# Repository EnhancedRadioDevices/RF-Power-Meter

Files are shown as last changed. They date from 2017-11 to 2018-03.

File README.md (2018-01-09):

Enhanced Radio Devices - RF Power Meter
=======

The ERD RF Power Meter is designed as an affordable RF Power Meter for use in cases where the precision of expensive professional equipment is not required.

The device is available to the host system as a USB serial device, which when accessed automatically prints the measured RF level.

This repository contains the source code to be compiled with AVR-GCC, and uploaded to the device via ATMEL's FLIP programmer or the dfu-programmer utility.

## Drivers
The Power Meter board is automatically recognized as a USB serial device under OSX and Linux, however, windows requires a driver to associate the device with the built in USB serial device drivers.

When first attaching the device to a windows based host, windows will attempt to find a driver and fail. You may then specify a driver. This is provided in ERD_RF_Power_Meter.inf.

Once you have installed the driver, the Power Meter will register as a COM port device under windows, and you may access it with any serial/terminal application of your preference.

### Windows Users
During the driver installation process on Windows 8 operating systems and above you may encounter *"The third-party INF does not contain digital signature information"* preventing the installation of the included driver.  The steps below outline the process for disabling driver signature enforcement on Windows 8/8.1 systems.

**NOTE:** If your system uses BitLocker Drive Encryption, you will need your encryption key to gain access to advanced settings to disable driver signature enforcement.

Windows 8 - Navigate to PC settings > General and look for the *Advanced startup* dialog.  Click the **Restart now** button to access the advanced startup settings.  Your system will now reboot.

Windows 8.1 - Navigate to PC settings > Update and Recovery > Recovery and look for the *Advanced startup* dialog.  Click the **Restart now** button to access the advanced startup settings.  Your system will now reboot.

After rebooting select Troubleshoot > Advanced options > Startup Settings, click the **Restart** button, your machine will reboot a second time.

After rebooting a second time you should be presented with the Windows Startup Settings dialog, choose *Disable driver signature enforcement* by pressing number `7` on your keyboard.  Your machine will reboot automatically.

Once rebooted, you should now be able to install the drviers as outlined above.  Once the appropriate driver is selected you will see a Windows Security dialog warning against the installation of the unsigned driver.  Click **Install this driver software anyway** to complete the driver installation.

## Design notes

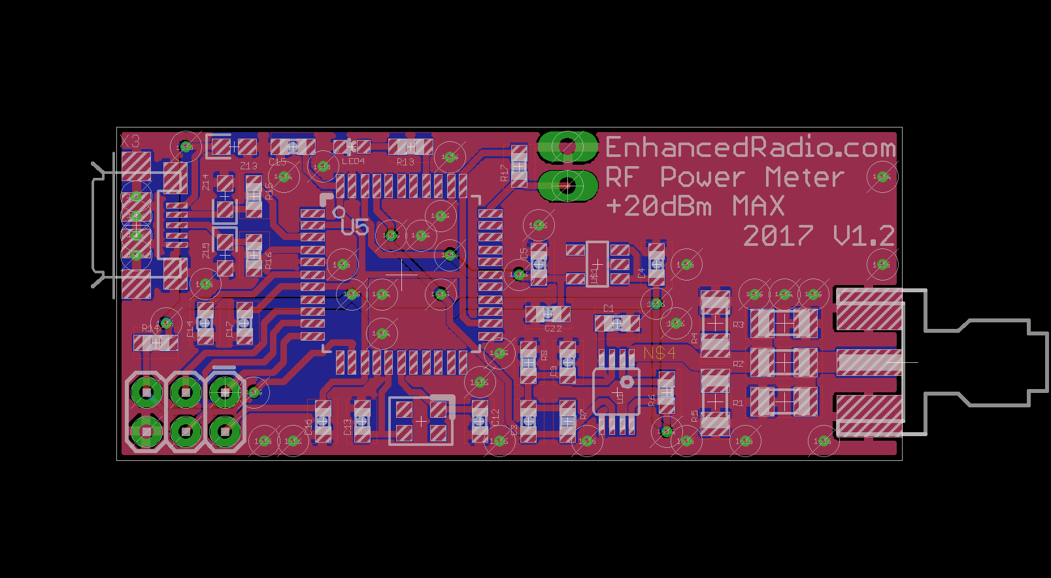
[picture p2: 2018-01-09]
Hardware/Board.png

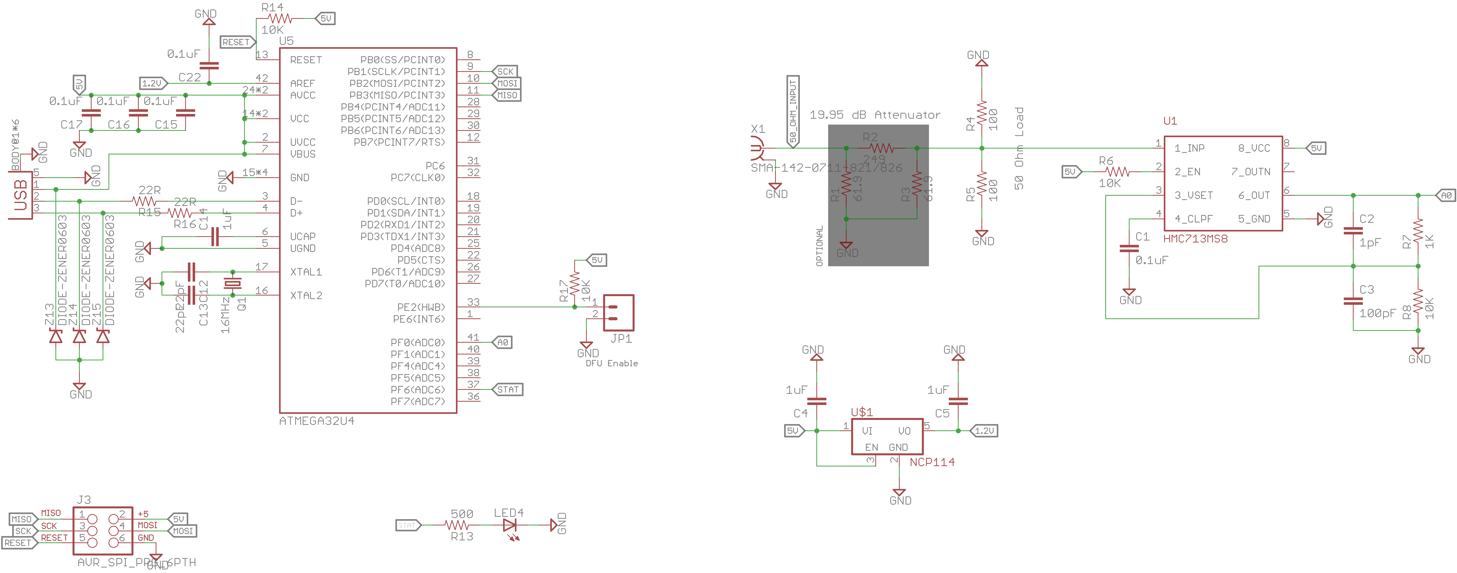
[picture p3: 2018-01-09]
Hardware/Schematic.png

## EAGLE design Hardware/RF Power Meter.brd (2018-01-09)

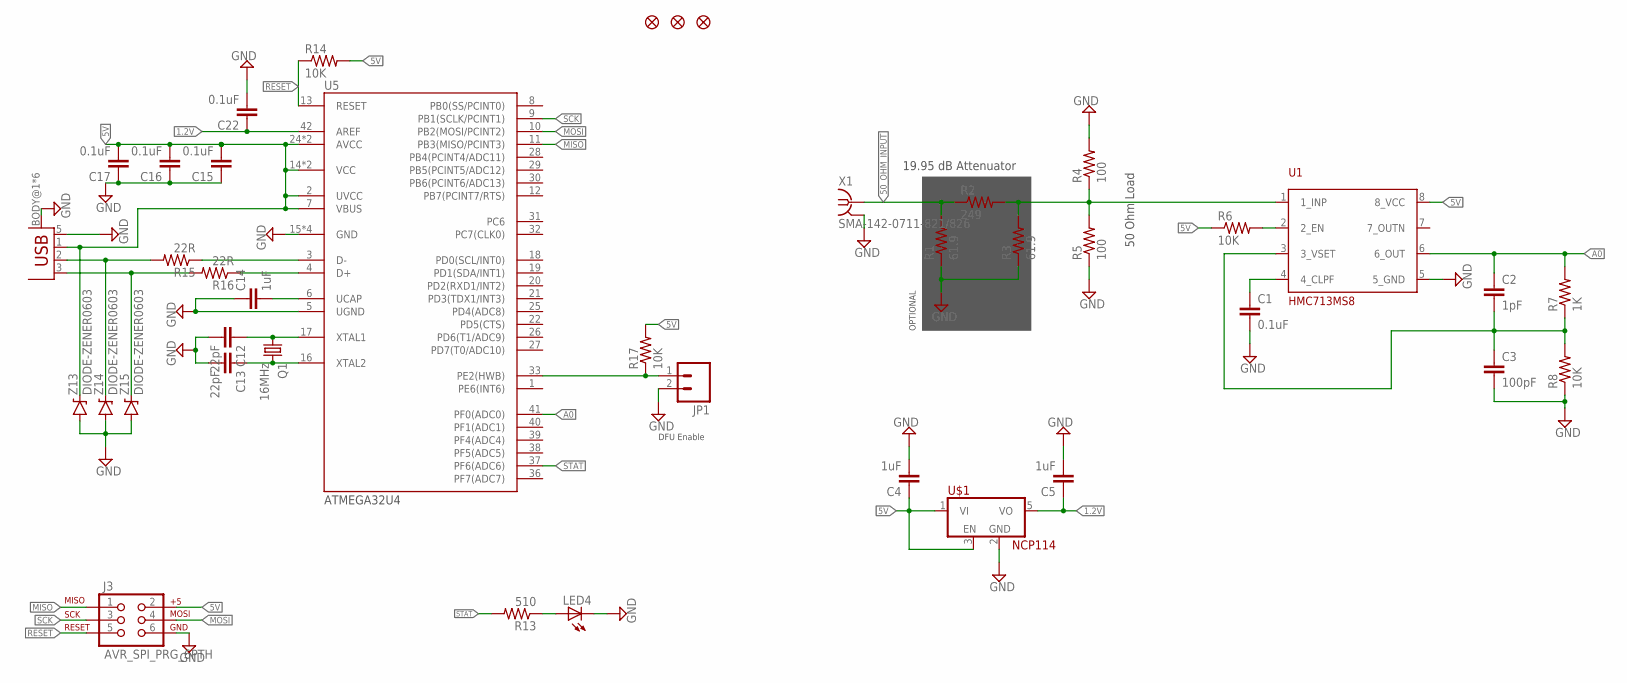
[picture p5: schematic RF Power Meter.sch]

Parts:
C1, C15, C16, C17, C22: 0.1uF; 0603-CAP
C2: 1pF; 0603-CAP
C3: 100pF; 0603-CAP
C4, C5, C14: 1uF; 0603-CAP
C12, C13: 22pF; 0603-CAP
J3: AVR_SPI_PRG_6PTH; 2X3
JP1: M02PTH3; 1X02_LONGPADS
JP2, JP3, JP4: FIDUCIAL1X2; FIDUCIAL-1X2
LED4: LED0603; LED-0603
Q1: 16MHz; CRYSTAL_3.2X2.5
R1, R3: 61.9; 1206
R2: 249; 1206
R4, R5: 100; 1206
R6, R8, R14, R17: 10K; 0603-RES
R7: 1K; 0603-RES
R13: 510; 0603-RES
R15, R16: 22R; 0603-RES
U1: HMC713MS8; MSOP-8
U5: ATMEGA32U4; TQFP-44
U$1: NCP114; SOT-23-5
X1: SMA-142-0711-821/826; J502-ND-142-0711-821/826
X3: USB-MICROB; USB-MICROB-10118192
Z13, Z14, Z15: DIODE-ZENER0603; 0603-DIODE

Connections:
1.2V: C5.1, C22.1, U5.42 (AREF), U$1.5 (VO)
5V: C4.1, C15.2, C16.2, C17.2, J3.2, R6.1, R14.2, R17.2, U1.8 (8_VCC), U5.2 (UVCC), U5.7 (VBUS), U5.14 (VCC), U5.24 (AVCC), U5.34 (VCC), U5.44 (AVCC), U$1.1 (VI), U$1.3 (EN), X3.1 (VBUS), Z13.C
50_OHM_INPUT: R1.2, R2.1, X1.1
A0: C2.1, R7.2, U1.6 (6_OUT), U5.41 (PF0(ADC0))
GND: C1.2, C3.2, C4.2, C5.2, C12.2, C13.2, C14.1, C15.1, C16.1, C17.1, C22.2, J3.6, JP1.2, LED4.C, R1.1, R3.1, R4.2, R5.1, R8.1, U1.5 (5_GND), U5.5 (UGND), U5.15 (GND), U5.23 (GND), U5.35 (GND), U5.43 (GND), U$1.2 (GND), X1.G@1 (2), X1.G@2 (2), X1.G@3 (2), X1.G@4 (2), X3.5 (GND), X3.BODY@1 (BODY), X3.BODY@2 (BODY), X3.BODY@3 (BODY), X3.BODY@4 (BODY), X3.BODY@5 (BODY), X3.BODY@6 (BODY), Z13.A, Z14.A, Z15.A
MISO: J3.1, U5.11 (PB3(MISO/PCINT3))
MOSI: J3.4, U5.10 (PB2(MOSI/PCINT2))
unnamed: R2.2, R3.2, R4.1, R5.2, U1.1 (1_INP)
unnamed: R6.2, U1.2 (2_EN)
unnamed: C1.1, U1.4 (4_CLPF)
unnamed: C2.2, C3.1, R7.1, R8.2, U1.3 (3_VSET)
unnamed: LED4.A, R13.1
unnamed: C12.1, Q1.P$1 (1), U5.17 (XTAL1)
unnamed: C13.1, Q1.P$3 (2), U5.16 (XTAL2)
unnamed: R15.2, X3.2 (D-), Z14.C
unnamed: C14.2, U5.6 (UCAP)
unnamed: R16.2, X3.3 (D+), Z15.C
unnamed: R16.1, U5.4 (D+)
unnamed: R15.1, U5.3 (D-)
unnamed: JP1.1, R17.1, U5.33 (PE2(HWB))
RESET: J3.5, R14.1, U5.13 (RESET)
SCK: J3.3, U5.9 (PB1(SCLK/PCINT1))
STAT: R13.2, U5.37 (PF6(ADC6))

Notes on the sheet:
OPTIONAL
19.95 dB Attenuator
50 Ohm Load
DFU Enable

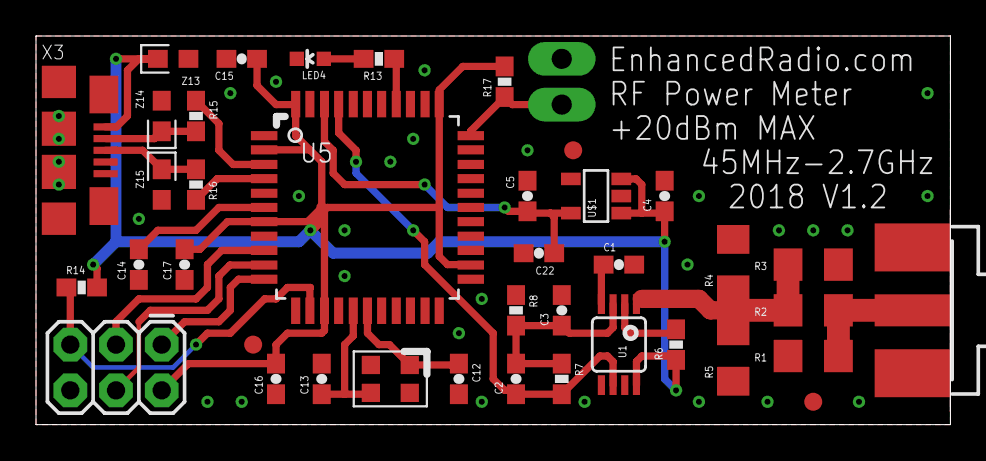
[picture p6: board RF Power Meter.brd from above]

Board: 2 copper layers, 50.8 x 21.6 mm, 40 parts (0 on the bottom side), 23 nets.

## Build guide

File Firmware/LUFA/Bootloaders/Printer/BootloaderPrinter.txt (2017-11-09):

/** \file
 *
 *  This file contains special DoxyGen information for the generation of the main page and other special
 *  documentation pages. It is not a project source file.
 */

/** \mainpage Printer Class USB AVR Bootloader
 *
 *  \section Sec_Compat Demo Compatibility:
 *
 *  The following list indicates what microcontrollers are compatible with this demo.
 *
 *  \li Series 7 USB AVRs (AT90USBxxx7)
 *  \li Series 6 USB AVRs (AT90USBxxx6)
 *  \li Series 4 USB AVRs (ATMEGAxxU4)
 *  \li Series 2 USB AVRs (AT90USBxx2, ATMEGAxxU2)
 *
 *  \section Sec_Info USB Information:
 *
 *  The following table gives a rundown of the USB utilization of this demo.
 *
 *  <table>
 *   <tr>
 *    <td><b>USB Mode:</b></td>
 *    <td>Device</td>
 *   </tr>
 *   <tr>
 *    <td><b>USB Class:</b></td>
 *    <td>Printer Class</td>
 *   </tr>
 *   <tr>
 *    <td><b>USB Subclass:</b></td>
 *    <td>Printer Subclass</td>
 *   </tr>
 *   <tr>
 *    <td><b>Relevant Standards:</b></td>
 *    <td>USBIF Printer Class Standard</td>
 *   </tr>
 *   <tr>
 *    <td><b>Supported USB Speeds:</b></td>
 *    <td>Full Speed Mode</td>
 *   </tr>
 *  </table>
 *
 *  \section Sec_Description Project Description:
 *
 *  This bootloader enumerates to the host as a Generic Text Only Printer device, capable of reading and parsing
 *  "printed" plain-text Intel HEX files to load firmware onto the AVR.
 *
 *  Out of the box this bootloader builds for the AT90USB1287 with an 8KB bootloader section size, and will fit
 *  into 4KB of bootloader space. If you wish to alter this size and/or change the AVR model, you will need to
 *  edit the MCU, FLASH_SIZE_KB and BOOT_SECTION_SIZE_KB values in the accompanying makefile.
 *
 *  When the bootloader is running, the board's LED(s) will flash at regular intervals to distinguish the
 *  bootloader from the normal user application.
 *
 *  \section Sec_Running Running the Bootloader
 *
 *  On the USB AVR8 devices, setting the \c HWBE device fuse will cause the bootloader to run if the \c HWB pin of
 *  the AVR is grounded when the device is reset.
 *
 *  The are two behaviours of this bootloader, depending on the device's fuses:
 *
 *  <b>If the device's BOOTRST fuse is set</b>, the bootloader will run any time the system is reset from
 *  the external reset pin, unless no valid user application has been loaded. To initiate the bootloader, the
 *  device's external reset pin should be grounded momentarily.
 *
 *  <b>If the device's BOOTRST fuse is not set</b>, the bootloader will run only if initiated via a software
 *  jump, or if the \c HWB pin was low during the last device reset (if the \c HWBE fuse is set).
 *
 *  For board specific exceptions to the above, see below.
 *
 *  \subsection SSec_XPLAIN Atmel Xplain Board
 *  Ground the USB AVR JTAG's \c TCK pin to ground when powering on the board to start the bootloader. This assumes the
 *  \c HWBE fuse is cleared and the \c BOOTRST fuse is set as the HWBE pin is not user accessible on this board.
 *
 *  \subsection SSec_Leonardo Arduino Leonardo Board
 *  Ground \c IO13 when powering the board to start the bootloader. This assumes the \c HWBE fuse is cleared and the
 *  \c BOOTRST fuse is set as the HWBE pin is not user accessible on this board.
 *
 *  \section Sec_Installation Driver Installation
 *
 *  This bootloader uses the Generic Text-Only printer drivers inbuilt into all modern operating systems, thus no
 *  additional drivers need to be supplied for correct operation.
 *
 *  \section Sec_HostApp Host Controller Application
 *
 *  This bootloader is compatible with Notepad under Windows, and the command line \c lpr utility under Linux.
 *
 *  \subsection SSec_Notepad Notepad (Windows)
 *
 *  While most text applications under Windows will be compatible with the bootloader, the inbuilt Notepad utility
 *  is recommended as it will introduce minimal formatting changes to the output stream. To program with Notepad,
 *  open the target HEX file and print it to the Generic Text Only printer device the bootloader creates.
 *
 *  \subsection SSec_LPR LPR (Linux)
 *
 *  While the CUPS framework under Linux will enumerate the bootloader as a Generic Text-Only printer, many
 *  applications will refuse to print to the device due to the lack of rich formatting options available. As a result,
 *  under Linux HEX files must be printed via the low level \c lpr utility instead.
 *
 *  \code
 *  cat Mouse.hex | lpr
 *  \endcode
 *
 *  \section Sec_API User Application API
 *
 *  Several user application functions for FLASH and other special memory area manipulations are exposed by the bootloader,
 *  allowing the user application to call into the bootloader at runtime to read and write FLASH data.
 *
 *  By default, the bootloader API jump table is located 32 bytes from the end of the device's FLASH memory, and follows the
 *  following layout:
 *
 *  \code
 *  #define BOOTLOADER_API_TABLE_SIZE          32
 *  #define BOOTLOADER_API_TABLE_START         ((FLASHEND + 1UL) - BOOTLOADER_API_TABLE_SIZE)
 *  #define BOOTLOADER_API_CALL(Index)         (void*)((BOOTLOADER_API_TABLE_START + (Index * 2)) / 2)
 *
 *  void    (*BootloaderAPI_ErasePage)(uint32_t Address)               = BOOTLOADER_API_CALL(0);
 *  void    (*BootloaderAPI_WritePage)(uint32_t Address)               = BOOTLOADER_API_CALL(1);
 *  void    (*BootloaderAPI_FillWord)(uint32_t Address, uint16_t Word) = BOOTLOADER_API_CALL(2);
 *  uint8_t (*BootloaderAPI_ReadSignature)(uint16_t Address)           = BOOTLOADER_API_CALL(3);
 *  uint8_t (*BootloaderAPI_ReadFuse)(uint16_t Address)                = BOOTLOADER_API_CALL(4);
 *  uint8_t (*BootloaderAPI_ReadLock)(void)                            = BOOTLOADER_API_CALL(5);
 *  void    (*BootloaderAPI_WriteLock)(uint8_t LockBits)               = BOOTLOADER_API_CALL(6);
 *
 *  #define BOOTLOADER_MAGIC_SIGNATURE_START   (BOOTLOADER_API_TABLE_START + (BOOTLOADER_API_TABLE_SIZE - 2))
 *  #define BOOTLOADER_MAGIC_SIGNATURE         0xDCFB
 *
 *  #define BOOTLOADER_CLASS_SIGNATURE_START   (BOOTLOADER_API_TABLE_START + (BOOTLOADER_API_TABLE_SIZE - 4))
 *  #define BOOTLOADER_PRINTER_SIGNATURE       0xDF20
 *
 *  #define BOOTLOADER_ADDRESS_START           (BOOTLOADER_API_TABLE_START + (BOOTLOADER_API_TABLE_SIZE - 8))
 *  #define BOOTLOADER_ADDRESS_LENGTH          4
 *  \endcode
 *
 *  From the application the API support of the bootloader can be detected by reading the FLASH memory bytes located at address
 *  \c BOOTLOADER_MAGIC_SIGNATURE_START and comparing them to the value \c BOOTLOADER_MAGIC_SIGNATURE. The class of bootloader
 *  can be determined by reading the FLASH memory bytes located at address \c BOOTLOADER_CLASS_SIGNATURE_START and comparing them
 *  to the value \c BOOTLOADER_PRINTER_SIGNATURE. The start address of the bootloader can be retrieved by reading the bytes of FLASH
 *  memory starting from address \c BOOTLOADER_ADDRESS_START.
 *
 *  \subsection SSec_API_MemLayout Device Memory Map
 *  The following illustration indicates the final memory map of the device when loaded with the bootloader.
 *
 *  \verbatim
 *  +----------------------------+ 0x0000
 *  |                            |
 *  |                            |
 *  |                            |
 *  |                            |
 *  |                            |
 *  |                            |
 *  |                            |
 *  |                            |
 *  |      User Application      |
 *  |                            |
 *  |                            |
 *  |                            |
 *  |                            |
 *  |                            |
 *  |                            |
 *  |                            |
 *  +----------------------------+ FLASHEND - BOOT_SECTION_SIZE
 *  |                            |
 *  |   Bootloader Application   |
 *  | (Not User App. Accessible) |
 *  |                            |
 *  +----------------------------+ FLASHEND - 96
 *  |   API Table Trampolines    |
 *  | (Not User App. Accessible) |
 *  +----------------------------+ FLASHEND - 32
 *  |    Bootloader API Table    |
 *  |   (User App. Accessible)   |
 *  +----------------------------+ FLASHEND - 8
 *  |   Bootloader ID Constants  |
 *  |   (User App. Accessible)   |
 *  +----------------------------+ FLASHEND
 *  \endverbatim
 *
 *
 *  \section Sec_KnownIssues Known Issues:
 *
 *  \par On Linux machines, new firmware fails to be sent to the device via CUPS.
 *  Only a limited subset of normal printer functionality is exposed via the
 *  bootloader, causing CUPS to reject print requests from applications that
 *  are unable to handle true plain-text printing. For best results, the low
 *  level \c lpr command should be used to print new firmware to the bootloader.
 *
 *  \section Sec_Options Project Options
 *
 *  The following defines can be found in this demo, which can control the demo behaviour when defined, or changed in value.
 *
 *  <table>
 *   <tr>
 *    <td>
 *     None
 *    </td>
 *   </tr>
 *  </table>
 */

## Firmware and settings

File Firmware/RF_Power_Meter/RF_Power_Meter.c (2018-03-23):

/* Enhanced Radio Devices */
/* 2018 by Nigel Vander Houwen <nigel@enhancedradio.com> */

#include "RF_Power_Meter.h"

// Main Scheduling Interrupt
ISR(TIMER1_COMPA_vect){
	timer++;

	if ((timer) % (READ_RF_DELAY * PRINTING_RATE) == 0){ schedule_read_rf = 1; }
}

// Main program entry point.
int main(void) {
	// Store our reset vector for reference
	// See ATmega32u4 Datasheet p.59 for values
	BOOT_RESET_VECTOR = MCUSR;
	MCUSR = 0;

	// Initialize some variables
	int16_t BYTE_IN = -1;
	DATA_IN = malloc(DATA_BUFF_LEN);

	// Set up timer 1 for 0.25s interrupts
	TCCR1A = 0b00000000; // No pin changes on compare match
	TCCR1B = 0b00001010; // Clear timer on compare match, clock /8
	TCCR1C = 0b00000000; // No forced output compare
	OCR1A = 31250; // Set timer clear at this count value
	TCNT1 = 0;
	TIMSK1 = 0b00000010; // Enable interrupts on the A compare match

	Watchdog_Disable();
	wdt_reset();
	Watchdog_Enable();

	// Divide 16MHz crystal down to 1MHz for CPU clock.
	clock_prescale_set(clock_div_16);

	// Init USB hardware and create a regular character stream for the
	// USB interface so that it can be used with the stdio.h functions
	USB_Init();
	CDC_Device_CreateStream(&VirtualSerial_CDC_Interface, &USBSerialStream);
	run_lufa();

	// Enable interrupts
	GlobalInterruptEnable();

	// Short delay during startup
	_delay_ms(2000);

	// Print startup message
	printPGMStr(PSTR(SOFTWARE_STR));
	fprintf(&USBSerialStream, " V%s,%s", HARDWARE_VERS, SOFTWARE_VERS);
	run_lufa();

	// Configure LED Pin
	DDRF |= (1 << LED);
	Set_LED(0);

	// Enable the ADC
	ADCSRA = (1<<ADEN) | (1<<ADPS2) | (1<<ADPS1) | (1<<ADPS0); // Enable ADC, clocked by /128 divider
	
	// Check that the EEPROM has been initialized
	if (eeprom_read_byte((uint8_t*)(EEPROM_OFFSET_EEPROM_INIT)) != EEPROM_VERS) {
		printPGMStr(PSTR("\r\nEEPROM not initialized. Initializing..."));
		run_lufa();
		EEPROM_Init();
		eeprom_update_byte((uint8_t*)(EEPROM_OFFSET_EEPROM_INIT), EEPROM_VERS);
	}
	
	// Load calibration values
	Load_RF_Calibration(1);
	
	run_lufa();

	INPUT_Clear();

// ~~~~~~~~~~~~~~~~~~~~~~~~~~~~~~~~~~~~~~~~~~~~
// ~~ Main system loop
// ~~~~~~~~~~~~~~~~~~~~~~~~~~~~~~~~~~~~~~~~~~~~

	for (;;) {
		// Read a byte from the USB serial stream
		BYTE_IN = CDC_Device_ReceiveByte(&VirtualSerial_CDC_Interface);

		// USB Serial stream will return <0 if no bytes are available.
		if (BYTE_IN >= 0) {
			// Echo the char we just received back out the serial stream so the user's 
			// console will display it.
			fputc(BYTE_IN, &USBSerialStream);

			// Switch on the input byte to determine what is is and what to do.
			switch (BYTE_IN) {
				case 8:
				case 127:
					// Handle Backspace chars.
					if (DATA_IN_POS > 0){
						DATA_IN_POS--;
						DATA_IN[DATA_IN_POS] = 0;
						printPGMStr(STR_Backspace);
					}
					break;

				case '\n':
				case '\r':
					// Newline, Parse our command
					INPUT_Parse();
					INPUT_Clear();
					break;

				case 3:
					// Ctrl-c bail out on partial command
					INPUT_Clear();
					break;
				
				case 27:
					// ESC Print menu
					PRINT_Help();
					INPUT_Clear();
				
				case 29:
					// Ctrl-] reset all eeprom values
					EEPROM_Reset();
					EEPROM_Init();
					INPUT_Clear();
					break;
					
				case 30:
					// Ctrl-^ jump into the bootloader
					// Disable the watchdog timer
					Watchdog_Disable();
					
					bootloader();
					break; // We should never get here...

				default:
					// Normal char buffering
					if (DATA_IN_POS < (DATA_BUFF_LEN - 1)) {
						DATA_IN[DATA_IN_POS] = BYTE_IN;
						DATA_IN_POS++;
						DATA_IN[DATA_IN_POS] = 0;
					} else {
						// Input is too long.
						printPGMStr(STR_Unrecognized);
						INPUT_Clear();
					}
					break;
			}
		}
		
		// Check for above threshold current usage
		if (schedule_read_rf && DATA_IN_POS == 0) {
			Set_LED(1);	
	
			// Collect ADC_AVG_POINTS samples and average them
			uint16_t average = 0;
			for (uint8_t i = 0; i < ADC_AVG_POINTS; i++) {
				average += ADC_Read_RF();
			}
			average = average / ADC_AVG_POINTS;
			
			// Convert the average reading into a voltage value referenced on ADC_V_REF
			float temp = (average * (ADC_V_REF / 1024.0));
			
			// Convert the voltage value into a dBm reading
			if (OUTPUTRAW == 0) {
				temp = (temp / RF_FREQ_SLOPE) - RF_FREQ_INTERCEPT + 19.95;
				fprintf(&USBSerialStream, "\r\n%.2f dBm", temp);
			} else {
				fprintf(&USBSerialStream, "\r\n%.3f V", temp);
			}
			
			schedule_read_rf = 0;
			
			Set_LED(0);
		}
		
		// Keep the LUFA USB stuff fed regularly.
		run_lufa();
		
		// Reset the watchdog
		wdt_reset();
	}
}

// ~~~~~~~~~~~~~~~~~~~~~~~~~~~~~~~~~~~~~~~~~~~~
// ~~ Command Parsing Functions
// ~~~~~~~~~~~~~~~~~~~~~~~~~~~~~~~~~~~~~~~~~~~~

// Flush out our data input buffer, reset our position variable, and print a new prompt.
static inline void INPUT_Clear(void) {
	memset(&DATA_IN[0], 0, sizeof(DATA_IN));
	DATA_IN_POS = 0;
	
	fprintf(&USBSerialStream, "\r\n\r\n");
}

// Parse out a single number argument
static inline long INPUT_Parse_num() {
	long temp = 0;
	uint8_t negative = 0;
	uint8_t num_started = 0;
	
	while (*DATA_IN != 0) {
		if (num_started == 0) { // Number hasn't started yet. Skip through non-number chars.
			if (*DATA_IN == '-') { negative = 1; num_started = 1; }
			if (*DATA_IN == '+') { negative = 0; num_started = 1; }
			if (*DATA_IN >= '0' && *DATA_IN <= '9') { temp = (temp * 10) + (*DATA_IN - '0'); num_started = 1; }
		} else { // Number has started. Continue reading until we hit a non-number.
			if (*DATA_IN >= '0' && *DATA_IN <= '9') {
				temp = (temp * 10) + (*DATA_IN - '0');
			} else {
				break;
			}
		}
		DATA_IN++;	
	}
	
	if (negative) { temp = temp * -1; }
	
	return temp;
}

// We've gotten a new command, parse out what they want.
static inline void INPUT_Parse(void) {
	// HELP - Print a basic help menu
	if (strncasecmp_P(DATA_IN, STR_Command_HELP, 4) == 0) {
		PRINT_Help();
		return;
	}
	// DEBUG - Print a report of debugging information, including EEPROM variables
	if (strncasecmp_P(DATA_IN, STR_Command_DEBUG, 10) == 0) {
		DEBUG_Dump();
		return;
	}
	// SETSLOPE - Update calibration slope value for the given frequency
	if (strncasecmp_P(DATA_IN, STR_Command_SETSLOPE, 8) == 0) {
		DATA_IN += 8;
		long span = INPUT_Parse_num();
		long slope = INPUT_Parse_num();
		if (span >= 0 && span <= 26 && slope >= 160 && slope <= 180) {
			EEPROM_Write_RF_Cal_Slope(span, (float)(slope / 10000.0));
			printPGMStr(STR_Slope_Set);
			return;
		}
	}
	// SETINTERCEPT - Update calibration intercept value for the given frequency	
	if (strncasecmp_P(DATA_IN, STR_Command_SETINTERCEPT, 12) == 0) {
		DATA_IN += 12;
		long span = INPUT_Parse_num();
		long intercept = INPUT_Parse_num();
		if (span >= 0 && span <= 26 && intercept >= 65 && intercept <= 75) {
			EEPROM_Write_RF_Cal_Intercept(span, intercept);
			printPGMStr(STR_Intercept_Set);
			return;
		}
	}
	// OUTPUTRAW - Toggle outputting raw voltage values instead of the calculated dBm values
	if (strncasecmp_P(DATA_IN, STR_Command_OUTPUTRAW, 9) == 0) {
		if (OUTPUTRAW == 0) {
			OUTPUTRAW = 1;
		} else {
			OUTPUTRAW = 0;
		}
		return;
	}
	// F - Set frequency to help calibrate readings
	if (*DATA_IN == 'F' || *DATA_IN == 'f') {
		DATA_IN += 1;
		uint16_t temp_freq = atoi(DATA_IN);
		if (temp_freq >= 1 && temp_freq < 2700) {
			printPGMStr(STR_Load_Cal);
			fprintf(&USBSerialStream, "%i", temp_freq);
			Load_RF_Calibration(temp_freq);
			return;
		}
	}
	// R - Set data printing rate
	if (*DATA_IN == 'R' || *DATA_IN == 'r') {
		DATA_IN += 1;
		uint16_t temp_rate = atoi(DATA_IN);
		if (temp_rate >= 1 && temp_rate <= 10) {
			printPGMStr(STR_Rate_Set);
			fprintf(&USBSerialStream, "%i seconds.", temp_rate);
			PRINTING_RATE = temp_rate;
			return;
		}
	}
	
	// If none of the above commands were recognized, print a generic error.
	printPGMStr(STR_Unrecognized);
}

// ~~~~~~~~~~~~~~~~~~~~~~~~~~~~~~~~~~~~~~~~~~~~
// ~~ Printing Functions
// ~~~~~~~~~~~~~~~~~~~~~~~~~~~~~~~~~~~~~~~~~~~~

// Print a summary of all ports status'
static inline void PRINT_Status(void) {

}

// Print a quick help command
static inline void PRINT_Help(void) {
	printPGMStr(STR_Help_Info);
}

// Print a PGM stored string
static inline void printPGMStr(PGM_P s) {
	char c;
	while((c = pgm_read_byte(s++)) != 0) fputc(c, &USBSerialStream);
}

// ~~~~~~~~~~~~~~~~~~~~~~~~~~~~~~~~~~~~~~~~~~~~
// ~~ EEPROM Functions
// ~~~~~~~~~~~~~~~~~~~~~~~~~~~~~~~~~~~~~~~~~~~~ 

// Reset all EEPROM values to 255
static inline void EEPROM_Reset(void) {
	for (uint16_t i = 0; i < 512; i++) {
		eeprom_update_byte((uint8_t*)(i), 255);
	}
}

// Initialize the EEPROM with default calibration values
static inline void EEPROM_Init(void) {
	for (uint8_t i = 0; i < 27; i++) {
		eeprom_update_byte((uint8_t*)(EEPROM_OFFSET_RF_CAL_SLOPE + i), RF_CAL_DEFAULTS_SLOPE[i]);
		eeprom_update_byte((uint8_t*)(EEPROM_OFFSET_RF_CAL_INTERCEPT + i), RF_CAL_DEFAULTS_INTERCEPT[i]);
	}
}

// Handle read/write of the RF slope value from EEPROM based on what frequency span we're in
static inline void EEPROM_Write_RF_Cal_Slope(uint8_t span, float value) {
	eeprom_update_byte((uint8_t*)(EEPROM_OFFSET_RF_CAL_SLOPE + span), (int)(value * 10000));
}
static inline float EEPROM_Read_RF_Cal_Slope(uint8_t span) {
	uint8_t RF_CAL_SLOPE = eeprom_read_byte((uint8_t*)(EEPROM_OFFSET_RF_CAL_SLOPE + span));
	// If the value seems out of range (uninitialized), default it to 0.0173
	if (RF_CAL_SLOPE < 160 || RF_CAL_SLOPE > 180) RF_CAL_SLOPE = 173;
	return (float)RF_CAL_SLOPE / 10000.0;
}

// Handle read/write of the RF intercept value from EEPROM based on what frequency span we're in
static inline void EEPROM_Write_RF_Cal_Intercept(uint8_t span, uint8_t value) {
	eeprom_update_byte((uint8_t*)(EEPROM_OFFSET_RF_CAL_INTERCEPT + span), value);
}
static inline uint8_t EEPROM_Read_RF_Cal_Intercept(uint8_t span) {
	uint8_t RF_CAL_INTERCEPT = eeprom_read_byte((uint8_t*)(EEPROM_OFFSET_RF_CAL_INTERCEPT + span));
	// If the value seems out of range (uninitialized), default it to 68
	if (RF_CAL_INTERCEPT < 65 || RF_CAL_INTERCEPT > 75) RF_CAL_INTERCEPT = 68;
	return RF_CAL_INTERCEPT;
}

// ~~~~~~~~~~~~~~~~~~~~~~~~~~~~~~~~~~~~~~~~~~~~
// ~~ Debugging Functions
// ~~~~~~~~~~~~~~~~~~~~~~~~~~~~~~~~~~~~~~~~~~~~

// Dump debugging data
static inline void DEBUG_Dump(void) {
	// Print hardware and software versions
	fprintf(&USBSerialStream, "\r\nHW V%s, SW V%s", HARDWARE_VERS, SOFTWARE_VERS);
	
	// Print eeprom version
	fprintf(&USBSerialStream, "\r\nEEPROM V%i", eeprom_read_byte((uint8_t*)(EEPROM_OFFSET_EEPROM_INIT)));
	
	// Print current calibration values
	printPGMStr(PSTR("\r\n\r\nCurrent Calibration Values: "));
	fprintf(&USBSerialStream, "%.4f - %i", RF_FREQ_SLOPE, RF_FREQ_INTERCEPT);
	
	// Print stored calibration values
	printPGMStr(PSTR("\r\n\r\nStored Calibration Values:"));
	for (uint8_t i = 0; i < 27; i++) {
		fprintf(&USBSerialStream, "\r\n%i:\t%.4f\t%i", i, EEPROM_Read_RF_Cal_Slope(i), EEPROM_Read_RF_Cal_Intercept(i));
	}
}

// ~~~~~~~~~~~~~~~~~~~~~~~~~~~~~~~~~~~~~~~~~~~~
// ~~ LED Functions
// ~~~~~~~~~~~~~~~~~~~~~~~~~~~~~~~~~~~~~~~~~~~~

// Set the output LED state
static inline void Set_LED(int8_t state) {
	if (state == 1) {
		PORTF |= (1 << LED);
	} else {
		PORTF &= ~(1 << LED);
	}
}

// ~~~~~~~~~~~~~~~~~~~~~~~~~~~~~~~~~~~~~~~~~~~~
// ~~ ADC Functions
// ~~~~~~~~~~~~~~~~~~~~~~~~~~~~~~~~~~~~~~~~~~~~

// Read RF Power Value
static inline int16_t ADC_Read_RF(void) {
	ADMUX = 0b00000000;
	ADCSRB = 0b00000000;
	ADCSRA |= (1<<ADSC); // Start first conversion (throw away)
	while (ADCSRA & (1<<ADSC)); // Wait for conversion to complete
	ADCSRA |= (1<<ADSC); // Start second conversion (valid)
	while (ADCSRA & (1<<ADSC)); // Wait for conversion to complete
	return ADCW;
}

// Load RF Calibration Values
static inline void Load_RF_Calibration(uint16_t freq) {
	// Convert freq in MHz to the span number
	uint8_t RF_FREQ_SPAN = (int)(freq / 100);
	
	// If the result ends up out of the valid range, default and print a message
	if (RF_FREQ_SPAN < 0 || RF_FREQ_SPAN > 26) {
		RF_FREQ_SPAN = 0;
		printPGMStr(STR_Freq_Range);
	}
	
	// Load calibration data corresponding to the selected span
	RF_FREQ_SLOPE = EEPROM_Read_RF_Cal_Slope(RF_FREQ_SPAN);
	RF_FREQ_INTERCEPT = EEPROM_Read_RF_Cal_Intercept(RF_FREQ_SPAN);
}

// ~~~~~~~~~~~~~~~~~~~~~~~~~~~~~~~~~~~~~~~~~~~~
// ~~ USB Functions
// ~~~~~~~~~~~~~~~~~~~~~~~~~~~~~~~~~~~~~~~~~~~~

// Run the LUFA USB tasks (except reading)
static inline void run_lufa(void) {
	//CDC_Device_ReceiveByte(&VirtualSerial_CDC_Interface);
	CDC_Device_USBTask(&VirtualSerial_CDC_Interface);
	USB_USBTask();
}

// Event handler for the library USB Connection event.
void EVENT_USB_Device_Connect(void) {
	// We're enumerated. Act on that as desired.
}

// Event handler for the library USB Disconnection event.
void EVENT_USB_Device_Disconnect(void) {
	// We're no longer enumerated. Act on that as desired.
}

// Event handler for the library USB Configuration Changed event.
void EVENT_USB_Device_ConfigurationChanged(void) {
	bool ConfigSuccess = true;
	ConfigSuccess &= CDC_Device_ConfigureEndpoints(&VirtualSerial_CDC_Interface);
	// USB is ready. Act on that as desired.
}

// Event handler for the library USB Control Request reception event.
void EVENT_USB_Device_ControlRequest(void) {
	CDC_Device_ProcessControlRequest(&VirtualSerial_CDC_Interface);
}

// ~~~~~~~~~~~~~~~~~~~~~~~~~~~~~~~~~~~~~~~~~~~~
// ~~ Watchdog Functions
// ~~~~~~~~~~~~~~~~~~~~~~~~~~~~~~~~~~~~~~~~~~~~

// Disables the watchdog timer
static inline void Watchdog_Disable(void) {
	cli();
	wdt_reset();
	MCUSR &= ~(1 << WDRF);
	WDTCSR |= (1 << WDCE) | (1 << WDE);
	WDTCSR = 0x00;
	sei();
}

// Enables the watchdog timer
static inline void Watchdog_Enable(void) {
	cli();
	wdt_reset();
	WDTCSR |= (1 << WDCE) | (1 << WDE);
	WDTCSR = (1 << WDE) | (1 << WDP3) | (1 << WDP0);
	sei();
}

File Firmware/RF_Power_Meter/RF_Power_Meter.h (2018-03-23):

/* Enhanced Radio Devices */
/* 2018 by Nigel Vander Houwen <nigel@enhancedradio.com> */

#ifndef _RF_Power_Meter_H_
#define _RF_Power_Meter_H_

// ~~~~~~~~~~~~~~~~~~~~~~~~~~~~~~~~~~~~~~~~~~~~
// ~~ Includes
// ~~~~~~~~~~~~~~~~~~~~~~~~~~~~~~~~~~~~~~~~~~~~

#include <avr/io.h>
#include <avr/wdt.h>
#include <avr/power.h>
#include <avr/sleep.h>
#include <avr/interrupt.h>
#include <util/delay.h>
#include <string.h>
#include <stdio.h>
#include <stdlib.h>
#include <avr/pgmspace.h>
#include <avr/eeprom.h>

#include <LUFA/Drivers/USB/USB.h>
#include <LUFA/Platform/Platform.h>

#include "Descriptors.h"

// ~~~~~~~~~~~~~~~~~~~~~~~~~~~~~~~~~~~~~~~~~~~~
// ~~ Macros
// ~~~~~~~~~~~~~~~~~~~~~~~~~~~~~~~~~~~~~~~~~~~~

// Enable ANSI color codes to be sent. Uses a small bit of extra program space for 
// storage of color codes/modified strings.
#define ENABLECOLORS

#define SOFTWARE_STR "\r\nERD RF Power Meter"
#define HARDWARE_VERS "1.2"
#define SOFTWARE_VERS "1.1"
#define EEPROM_VERS 1

// Serial input
#define DATA_BUFF_LEN 32

// ADC
#define ADC_V_REF 1.2
#define ADC_AVG_POINTS 5

// Pins
#define RF_ANALOG PF0
#define LED PF6

// Schedule
#define READ_RF_DELAY 4 // Ticks. ~1s

// EEPROM Offsets
// Calibration values
#define EEPROM_OFFSET_RF_CAL_SLOPE 0 // 1 byte * 27 Values (100MHz blocks) - Calibrate the frequency response slope
#define EEPROM_OFFSET_RF_CAL_INTERCEPT 27 // 1 byte * 27 Values (100MHz Blocks) - Calibrate the frequency response intercept
//#define EEPROM_OFFSET_NEXT 54
#define EEPROM_OFFSET_EEPROM_INIT 128

// ~~~~~~~~~~~~~~~~~~~~~~~~~~~~~~~~~~~~~~~~~~~~
// ~~ Globals
// ~~~~~~~~~~~~~~~~~~~~~~~~~~~~~~~~~~~~~~~~~~~~

// Timer
volatile unsigned long timer = 0;
// Schedule
volatile uint8_t schedule_read_rf = 0;

// Standard file stream for the CDC interface when set up, so that the
// virtual CDC COM port can be used like any regular character stream
// in the C APIs.
static FILE USBSerialStream;

// Help string
const char STR_Help_Info[] PROGMEM = "\r\n\"F<Frequency in MHz>\" to load the appropriate calibration values.\r\n\"R<1-10>\" to set the interval between readings (in seconds).\r\n\r\nVisit https://github.com/EnhancedRadioDevices/RF-Power-Meter for full docs.";

// Reused strings
#ifdef ENABLECOLORS
	const char STR_Unrecognized[] PROGMEM = "\r\n\x1b[31mINVALID COMMAND\x1b[0m";
	const char STR_Freq_Range[] PROGMEM = "\r\n\x1b[31mFrequency out of range. Using defaults.\x1b[0m";
#else
	const char STR_Unrecognized[] PROGMEM = "\r\nINVALID COMMAND";
	const char STR_Freq_Range[] PROGMEM = "\r\nFrequency out of range. Using defaults.";
#endif	

const char STR_Backspace[] PROGMEM = "\x1b[D \x1b[D";
const char STR_Load_Cal[] PROGMEM = "\r\nLoading calibration values for frequency: ";
const char STR_Rate_Set[] PROGMEM = "\r\nPrinting rate set to ";
const char STR_Slope_Set[] PROGMEM = "\r\nSlope set.";
const char STR_Intercept_Set[] PROGMEM = "\r\nIntercept set.";

// Command strings
const char STR_Command_HELP[] PROGMEM = "HELP";
const char STR_Command_DEBUG[] PROGMEM = "DEBUG";
const char STR_Command_SETSLOPE[] PROGMEM = "SETSLOPE";
const char STR_Command_SETINTERCEPT[] PROGMEM = "SETINTERCEPT";
const char STR_Command_OUTPUTRAW[] PROGMEM = "OUTPUTRAW";

// State Variables
char * DATA_IN;
uint8_t DATA_IN_POS = 0;
uint8_t BOOT_RESET_VECTOR = 0;
float RF_FREQ_SLOPE = 0.0;
uint8_t RF_FREQ_INTERCEPT = 0;
uint8_t PRINTING_RATE = 1;
uint8_t OUTPUTRAW = 0;

// Default calibration tables
const uint8_t RF_CAL_DEFAULTS_SLOPE[27] = \
		{173, 173, 173, 173, 173, 173, 173, 172, 172, 172, \
		 172, 172, 172, 172, 172, 171, 171, 171, 171, 171, \
		 171, 171, 171, 171, 172, 172, 172};
const uint8_t RF_CAL_DEFAULTS_INTERCEPT[27] = \
		{68, 68, 68, 68, 68, 69, 69, 69, 69, 70, \
		 70, 70, 70, 70, 70, 71, 70, 71, 73, 72, \
		 71, 71, 71, 71, 71, 72, 73};
		 
		 
/** LUFA CDC Class driver interface configuration and state information.
 * This structure is passed to all CDC Class driver functions, so that
 * multiple instances of the same class within a device can be
 * differentiated from one another.
 */ 
USB_ClassInfo_CDC_Device_t VirtualSerial_CDC_Interface = {
	.Config = {
		.ControlInterfaceNumber   = INTERFACE_ID_CDC_CCI,
		.DataINEndpoint           = {
			.Address          = CDC_TX_EPADDR,
			.Size             = CDC_TXRX_EPSIZE,
			.Banks            = 1,
		},
		.DataOUTEndpoint = {
			.Address          = CDC_RX_EPADDR,
			.Size             = CDC_TXRX_EPSIZE,
			.Banks            = 1,
		},
		.NotificationEndpoint = {
			.Address          = CDC_NOTIFICATION_EPADDR,
			.Size             = CDC_NOTIFICATION_EPSIZE,
			.Banks            = 1,
		},
	},
};

// ~~~~~~~~~~~~~~~~~~~~~~~~~~~~~~~~~~~~~~~~~~~~
// ~~ Prototypes
// ~~~~~~~~~~~~~~~~~~~~~~~~~~~~~~~~~~~~~~~~~~~~

// Set up a fake function that points to a program address where the bootloader should be
// based on the part type.
#ifdef __AVR_ATmega32U4__
	void (*bootloader)(void) = 0x3800;
#endif

// USB
static inline void run_lufa(void);

// EEPROM Read & Write
static inline void EEPROM_Reset(void);
static inline void EEPROM_Init(void);
static inline void EEPROM_Write_RF_Cal_Slope(uint8_t span, float value);
static inline float EEPROM_Read_RF_Cal_Slope(uint8_t span);
static inline void EEPROM_Write_RF_Cal_Intercept(uint8_t span, uint8_t value);
static inline uint8_t EEPROM_Read_RF_Cal_Intercept(uint8_t span);

// DEBUG
static inline void DEBUG_Dump(void);

// ADC
static inline int16_t ADC_Read_RF(void);
static inline void Load_RF_Calibration(uint16_t freq);

// LED
static inline void Set_LED(int8_t state);

// Output
static inline void printPGMStr(PGM_P s);
static inline void PRINT_Status(void);
static inline void PRINT_Help(void);

// Input
static inline long INPUT_Parse_num(void);
static inline void INPUT_Clear(void);
static inline void INPUT_Parse(void);

// Watchdog
static inline void Watchdog_Disable(void);
static inline void Watchdog_Enable(void);

#endif

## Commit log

2017-11-09 Initial commit. Basic functioning.
    [BoardDeviceMap.cfg, BootloaderDeviceMap.cfg]
2018-01-09 Changed organization of the repo. Updated USB VID/PID. Added RF Freq Range to silkscreen. Added board schematic and layout files.
    [BoardDeviceMap.cfg, BootloaderDeviceMap.cfg, RF Power Meter.brd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]
2018-03-22 Added EEPROM calibration tables based on frequency. Added command to set the current working frequency and load appropriate calibration data. Changed LED function to blink regularly with samples bein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
2018-03-22 Added OUTPUTRAW function to allow printing raw voltage readings rather than the calculated dBm values. Useful in calibration.
2018-03-23 Replaced placeholder calibration values. Added function to automatically init EEPROM with default calibration values if empty. Ready for new release.
    [RF_Power_Meter.c, RF_Power_Meter.h]

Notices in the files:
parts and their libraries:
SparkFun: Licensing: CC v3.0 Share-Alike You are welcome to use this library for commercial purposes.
